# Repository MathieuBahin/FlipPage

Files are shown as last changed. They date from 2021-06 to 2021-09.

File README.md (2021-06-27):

# FlipPage
Hello everyone,
I would like to share with you today a project that I developed for my needs.

This product let's you turn pages on your tablet with your feets. That's a game changer when you tried one, you no longer have to stop playing to turn a page etc.

I am a guitarist and I have a software (MobileSheets) on my tablet that allows me to display my scores on stage without the famous binder with pages that turn when there is wind.

Similar products exist on the market for a price too high for my taste. I have one but it is no longer compatible with my new tablet.

This page is here to explain how you can build one by yourself.

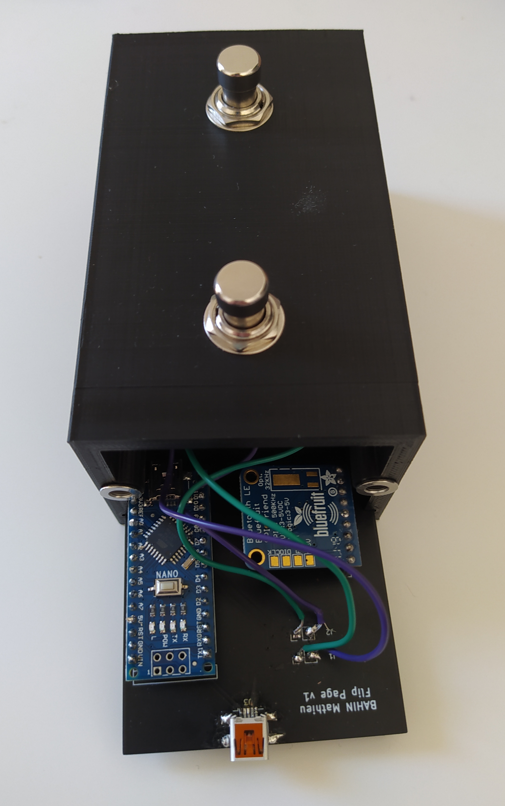
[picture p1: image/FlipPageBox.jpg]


## Electronics
What do we need ?
- a microcontroler
- 2 buttons
- a bluetooth module

I will be using an Arduino Nano for it's size and ease of programming.
Regarding the bluetooth module we need a module that is "HID" compatible. An HID module is meant to be a keyboard controler, mouse, etc. 

It won't work if your bluetooth module is not "HID" compatible.

After lots of research i found one : the [Adafruit Bluefruit LE UART](https://www.adafruit.com/product/2479)

Based on the nRF51822 bluetooth chip.

I decided to add an extra USB connector as a power input, you can try to use the one from the Arduino Nano if you wish.

### Components used

| Name |  Cost |
| --- |:-----:|
| Arduino Nano | $2  |
| [Bluefruit SPI BLE](https://www.adafruit.com/product/2479) | $17.5 |
| USB connector |  $0.2 |
| [Footswitch](https://www.ebay.fr/itm/262356324402) |  $4 |
| [Nut](https://www.amazon.fr/gp/product/B00WO7N4PA/) | $8|
| [Bolt](https://www.amazon.fr/gp/product/B073W7288P/) | $12|

I used a footswitch like this one :
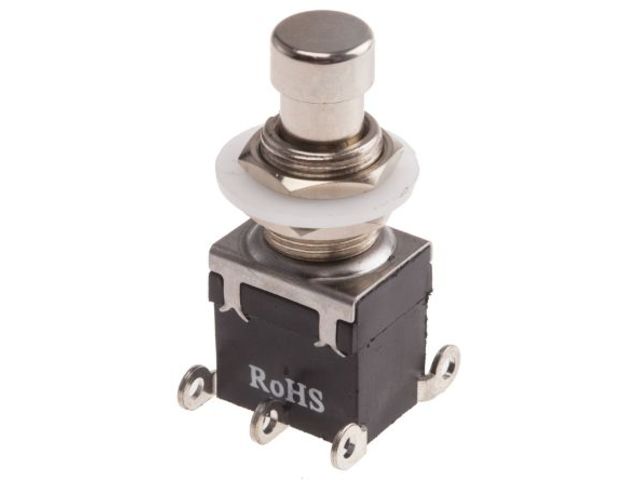
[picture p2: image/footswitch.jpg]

### KiCad schematic and routing
You will find the files in the folder KiCad.
I printed the PCB at [JLCPCB](https://jlcpcb.com/), reliable and low cost.

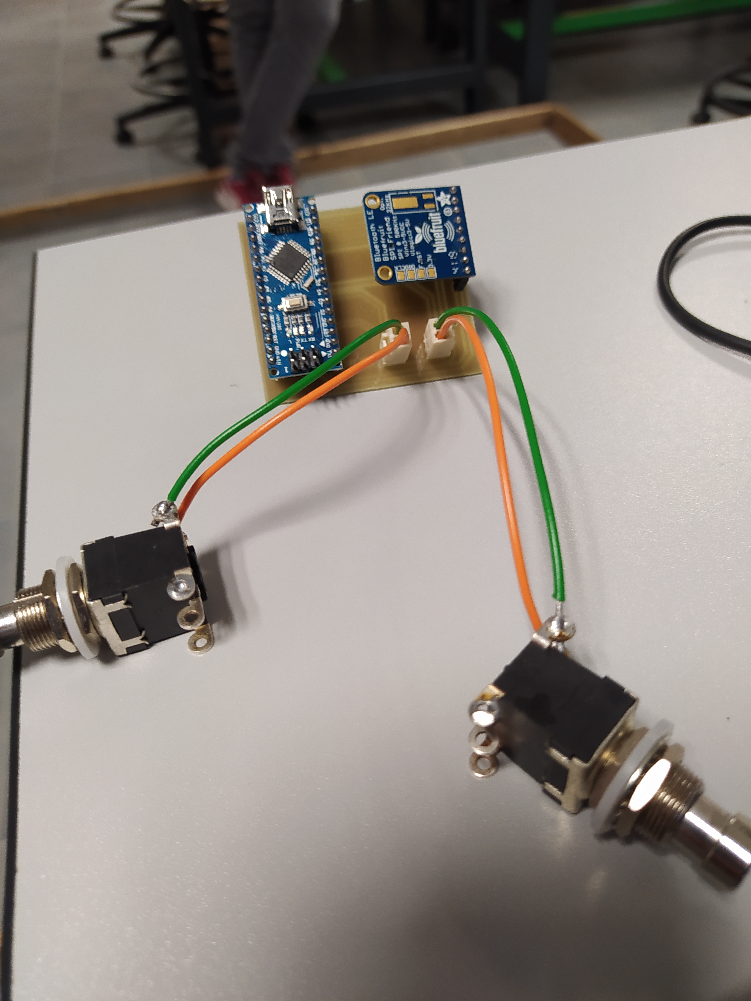
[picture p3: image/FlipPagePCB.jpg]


## Arduino development
You can use whatever IDE fits you, I used the Arduino IDE.

Add the lib to the libraries folder (generaly in Documents\Arduino\libraries).

Choose the Board : Arduino Nano and the processor that fits your card.

Then connect the Arduino (not the power usb connector) and compile/flash the software. 

You can open the Serial Monitor to see the initialisation.

Now you are done, the only thing left is the casing.

## 3D Printer
My 3D printer is a Creality Ender 3X I'm using black PLA.

You will find the Solidworks files in the folder associated.

You can make the assembly if you wish i didn't upload mine. (Also save the PCB in .step from KiCad to have a full assembly)

The box printing time is around 12h30 at 40%.

The top printing time is around 1h30 at 40%.

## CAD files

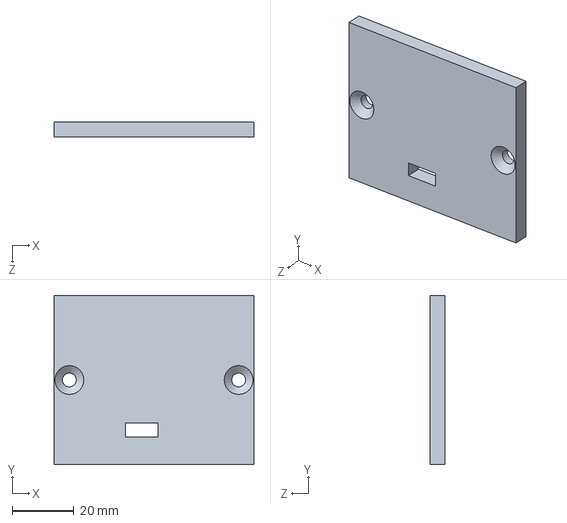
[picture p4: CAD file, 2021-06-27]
SolidWorks/Top.SLDPRT
65.0 x 55.0 x 5.00 mm

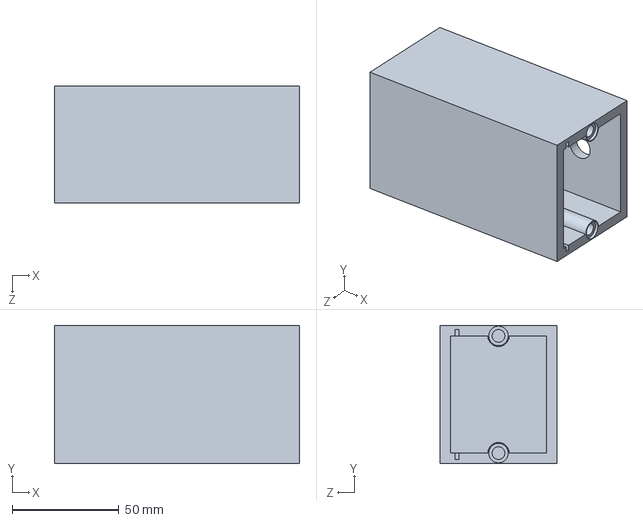
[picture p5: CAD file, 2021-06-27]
SolidWorks/Box.SLDPRT
115.0 x 65.0 x 55.0 mm

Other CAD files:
SolidWorks/Box.STL
SolidWorks/Top.STL

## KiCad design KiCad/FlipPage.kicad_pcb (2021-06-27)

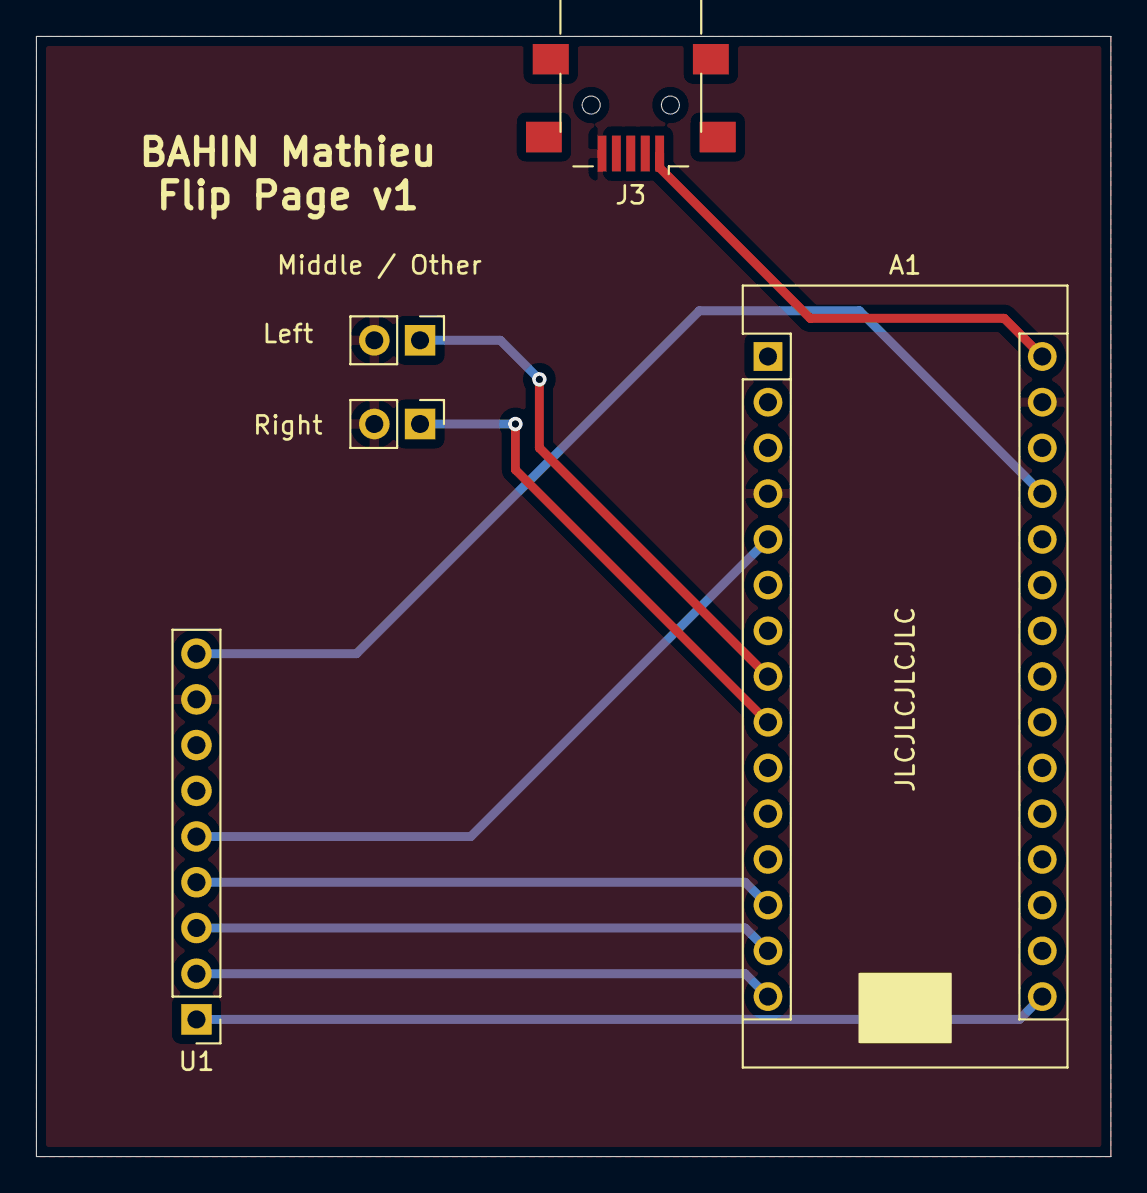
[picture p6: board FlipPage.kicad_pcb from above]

Board: 2 copper layers, 59.7 x 62.2 mm, 5 parts (0 on the bottom side), 10 nets.

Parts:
A1: Arduino_Nano_v3.x; Arduino_Nano_step
J1, J2: Conn_01x02_Male; PinHeader_1x02_P2.54mm_Vertical
J3: USB_B_Mini; USB_Mini-B_Lumberg_2486_01_Horizontal
U1: Bluefruit_SPI_Bluetooth; PinHeader_1x09_P2.54mm_Vertical

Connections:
unnamed: A1.5, U1.5
unnamed: A1.8, J1.1
unnamed: A1.9, J2.1
unnamed: A1.13, U1.4
unnamed: A1.14, U1.3
unnamed: A1.15, U1.2
unnamed: A1.16, U1.1
unnamed: A1.27, U1.9
unnamed: A1.4, A1.29, J1.2, J2.2, J3.5, U1.8
unnamed: A1.30, J3.1

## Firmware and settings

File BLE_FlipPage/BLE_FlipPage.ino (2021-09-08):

#include <Arduino.h>
#include <SPI.h>
#include "Adafruit_BLE.h"
#include "Adafruit_BluefruitLE_SPI.h"
#include "Adafruit_BluefruitLE_UART.h"

#include "BluefruitConfig.h"

#if SOFTWARE_SERIAL_AVAILABLE
  #include <SoftwareSerial.h>
#endif

#define FACTORYRESET_ENABLE         0
#define MINIMUM_FIRMWARE_VERSION    "0.6.6"

/* ...hardware SPI, using SCK/MOSI/MISO hardware SPI pins and then user selected CS/IRQ/RST */
Adafruit_BluefruitLE_SPI ble(BLUEFRUIT_SPI_CS, BLUEFRUIT_SPI_IRQ, BLUEFRUIT_SPI_RST);

#define D "4B" /* page up */
#define G "4E" /* page down */

#define BTNL 5
#define BTNR 6

/* called when the left button is pressed *
 *  send over BLE the command to flip the page
 */
void send_left(){
  ble.println(F("AT+BLEKEYBOARDCODE=00-00-" G "-00-00-00-00"));
  Serial.println("Sent left");
  //delay(500);
  ble.println(F("AT+BLEKEYBOARDCODE=00-00"));
  Serial.println("");
}

/* called when the right button is pressed *
 *  send over BLE the command to flip the page
 */
void send_right(){
  ble.println("AT+BLEKEYBOARDCODE=00-00-" D "-00-00-00-00");
  Serial.println("Sent right");
  ble.println("AT+BLEKEYBOARDCODE=00-00");
  Serial.println("");
}

int vl, vr; /* previous state */


void setup(void)
{

  Serial.begin(9600);
  /* Initialise the module */
  Serial.print(F("Initialising the Bluefruit BLE module: "));

  if ( !ble.begin(VERBOSE_MODE) )
  {
    Serial.println(F("Couldn't find Bluefruit, make sure it's in Command mode & check wiring?"));
    while(1);
  }
  Serial.println( F("OK!") );

  if ( FACTORYRESET_ENABLE )
  {
    /* Perform a factory reset to make sure everything is in a known state */
    Serial.println(F("Performing a factory reset: "));
    if ( ! ble.factoryReset() )
    {
      Serial.println(F("Couldn't factory reset"));
      while(1);
    }
  }

  /* Disable command echo from Bluefruit */
  ble.echo(false);

  /* Change the device name to make it easier to find */
  Serial.println(F("Setting device name to 'PageFlip1': ")); /*********************************** CHANGE NAME HERE ******************************/
  if (! ble.sendCommandCheckOK(F( "AT+GAPDEVNAME=FlipPage1" )) ) 
  {
    Serial.println(F("Could not set device name?"));
    while(1);
  }

  /* Enable HID Service */
  Serial.println(F("Enable HID Service (including Keyboard): "));
  if ( ble.isVersionAtLeast(MINIMUM_FIRMWARE_VERSION) )
  {
    if ( !ble.sendCommandCheckOK(F( "AT+BleHIDEn=On" ))) 
    {
      Serial.println(F("Could not enable Keyboard"));
      while(1);
    }
  }else
  {
    if (! ble.sendCommandCheckOK(F( "AT+BleKeyboardEn=On"  ))) 
    {
      Serial.println(F("Could not enable Keyboard"));
      while(1);
    }
  }

  /* Add or remove service requires a reset */
  Serial.println(F("Performing a SW reset (service changes require a reset): "));
  if (! ble.reset() ) 
  {
    Serial.println(F("Couldn't reset??"));
    while(1);
  }

  Serial.println();

  pinMode(BTNL, INPUT_PULLUP);
  pinMode(BTNR, INPUT_PULLUP);
  vr = digitalRead(5);
  vl = digitalRead(6);
  
  Serial.println(F("Configure IO pins : OK"));
  Serial.println();
}

/**************************************************************************/
/*!
    @brief  Constantly poll for new command or response data
*/
/**************************************************************************/
void loop(void)
{
  char sl, sr;
  sr = digitalRead(5);
  sl = digitalRead(6);

  if(sr != vr)
  { /* state changed */
    send_left();
    delay(700);
    vr = sr; /* save new state */
  }
  else
  {
    if(sl != vl)
    { /* state changed */
      send_right();
      delay(700);
      vl = sl; /* save new state */
    }
  } 
}

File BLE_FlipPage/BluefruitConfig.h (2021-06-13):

// COMMON SETTINGS
// ----------------------------------------------------------------------------------------------
// These settings are used in both SW UART, HW UART and SPI mode
// ----------------------------------------------------------------------------------------------
#define BUFSIZE                        128   // Size of the read buffer for incoming data
#define VERBOSE_MODE                   true  // If set to 'true' enables debug output


// SOFTWARE UART SETTINGS
// ----------------------------------------------------------------------------------------------
// The following macros declare the pins that will be used for 'SW' serial.
// You should use this option if you are connecting the UART Friend to an UNO
// ----------------------------------------------------------------------------------------------
#define BLUEFRUIT_SWUART_RXD_PIN       9    // Required for software serial!
#define BLUEFRUIT_SWUART_TXD_PIN       10   // Required for software serial!
#define BLUEFRUIT_UART_CTS_PIN         11   // Required for software serial!
#define BLUEFRUIT_UART_RTS_PIN         -1   // Optional, set to -1 if unused


// HARDWARE UART SETTINGS
// ----------------------------------------------------------------------------------------------
// The following macros declare the HW serial port you are using. Uncomment
// this line if you are connecting the BLE to Leonardo/Micro or Flora
// ----------------------------------------------------------------------------------------------
#ifdef Serial1    // this makes it not complain on compilation if there's no Serial1
  #define BLUEFRUIT_HWSERIAL_NAME      Serial1
#endif


// SHARED UART SETTINGS
// ----------------------------------------------------------------------------------------------
// The following sets the optional Mode pin, its recommended but not required
// ----------------------------------------------------------------------------------------------
#define BLUEFRUIT_UART_MODE_PIN        12    // Set to -1 if unused


// HARDWARE SPI SETTINGS
// ----------------------------------------------------------------------------------------------
// The following macros declare the pins to use for HW SPI communication.
// SCK, MISO and MOSI should be connected to the HW SPI pins on the Uno, etc.
// This should be used with nRF51822 based Bluefruit LE modules that use SPI.
// ----------------------------------------------------------------------------------------------
#define BLUEFRUIT_SPI_CS               10
#define BLUEFRUIT_SPI_IRQ              2
#define BLUEFRUIT_SPI_RST              -1    // Optional but recommended, set to -1 if unused

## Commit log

2021-06-13 Files from the project
    [Box.SLDPRT, Box.STL, FlipPage.kicad_pcb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]
2021-06-16 Added Front Silk Info for wiring
    [FlipPage.kicad_pcb]
2021-06-16 Changes from wiring info addition
    [pédale_ble-B_Cu.gbl, pédale_ble-B_Mask.gbs, pédale_ble-B_Paste.gbp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]
2021-06-16 Added KiCad Documentation
2021-06-27 [UPDATE] top and box didn't close all the way
    Removed the hole on the top piece and added a hole on the box side
    [Box.SLDPRT, Box.STL, Top.SLDPRT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]
2021-06-27 Modified links of libs
    [FlipPage.kicad_pcb, FlipPage.sch]
2021-09-08 Autoconnect when plugged in no need to forget device on tablet
    Before you had to "forget" the device on the tablet
